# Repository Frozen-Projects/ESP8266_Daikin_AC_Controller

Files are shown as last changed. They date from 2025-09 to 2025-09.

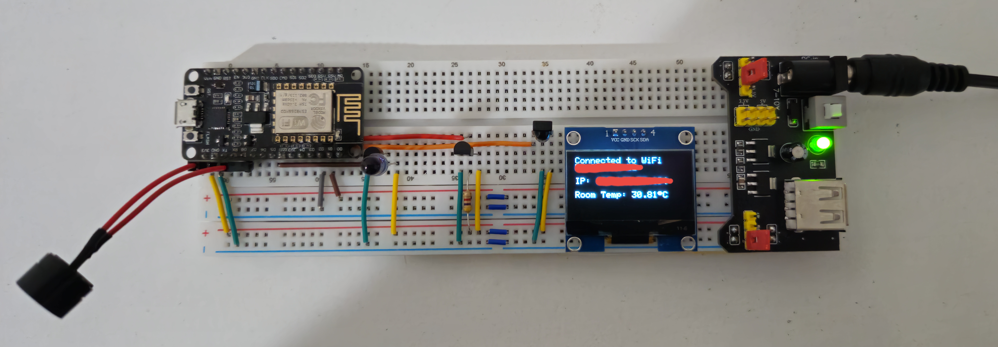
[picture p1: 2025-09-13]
Docs/ESP8266_Daikin_AC_Controller.jpg

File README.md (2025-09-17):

# ESP8266_Daikin_Controller
ESP8266 based Daikin AC Controller.

## FEATURES
- Turn on and off AC.
- Change temperature.
- Change fan speed.
- Set, change or clear auto off timer.
- It synchronized with original remote controller. (When you change something from remote controller, it will apply to ESP8266. But you can't see ESP8266 based changes on remote controller because it doesn't have an IR receiver. It just holds configurations.)
- Get room temperature with sensor (it refreshes at every 60 seconds).
- It has a web panel and API.

## LIBRARIES
You can install them from Arduino IDE libraries section.
- IRremoteESP8266 : https://github.com/crankyoldgit/IRremoteESP8266
- (Optional for temperature sensor) DallasTemperature : https://github.com/milesburton/Arduino-Temperature-Control-Library
- (Optional for temperature sensor) OneWire : https://www.pjrc.com/teensy/td_libs_OneWire.html
- (Optional for OLED) Adafruit GFX Lbrary
- (Optional for OLED) Adafruit SSD1305 / 1306 / SH110X

## IDE PLUGINS (OPTINAL IF YOU WANT TO STORE HTML AS A FILE)
- LittleFS Uploader : https://github.com/earlephilhower/arduino-littlefs-upload/releases/tag/1.5.4

## LittleFS USAGE (OPTINAL IF YOU WANT TO STORE HTML AS A FILE)
- Close Arduino IDE
- Move downloaded .vsix file to ``C:\Users\USERNAME\.arduinoIDE\plugins`` (not "plugin-storage". you can create "plugins" folder if you don't have already.)
- Open Arduino IDE
- Press ``CTRL + SHIFT + P`` buttons to open plugins list.
- Search LittleFS.
- Your files should be in ``SketchFolder/data``. This path is constant. Don't change it. If you delete something from there and do upload, it will remove that files.

## ARDUINO IDE ESP8266 INSTALLATION
- Add this to ``Arduino IDE / File / Preferences / Additional Boards Manager URLs`` ``http://arduino.esp8266.com/stable/package_esp8266com_index.json``
- Install ESP8266 Boards from ``Arduino IDE / Tools / Boards Manager / Search "esp8266 by ESP8266 Community"``
- Select ``NodeMCU MCU 1.0 (ESP-12E Module) as target device.``
- If Windows 11 can't see ESP8266 correctly in ``Device Manager``, you have to install this driver.
Unzip driver, right click device, select update driver, choose driver folder. </br> https://www.silabs.com/software-and-tools/usb-to-uart-bridge-vcp-drivers?tab=downloads

## HARDWARES
- 1X ESP8266 NodeMCU (ESP32 doesn't work with IRremoteESP8266. You can track its support from its issues)
- 1X 5mm 940nm 80 mW IR LED (Blue LED in scheme) (Pins: Long leg is (+) and short leg s (- / GRD)
- 1X S8050 Transistor (Transistor with N sign in scheme) (Pins: Emitter - Base - Collector)
- 1X 4.7K ohm Resistor
- 1X Breadboard (I used big one)
- 1X IR Receiver to sync. with original remote controller.
- (Optional) 1X Dallas DS1820 Temperature Sensor (Pins: GND - DQ - VDD)
- (Optional) OLED Display to print connected WiFi and LAN IP Address.
- (Optional) 1X Female barrel jack or Breadboard Power Supply Module for easy power delivery. You know, ESP8266'e USB input requires 3.3V input and finding that adapter can be hard. This allow me to use 5V adapters. I used power supply module.

## INFO ABOUT PHOTOGRAPH
Connection scheme is same with Fritzing but I did some cable management and used power module for cleaner product.

## UI Preview
index.html file and Github Pages show what UI will look like when you install this .ino file to your ESP8266. Preview file generated from GitHub Copilot. So, there can be some little differences. Auto-Off Timer Selection Box will open when AC is on.

## ROADMAP
HiveMQ based MQTT for remote access and mobile app. </br>
I have CGN IP. So, I needed to deploy a tunnelling solution to access it from outside of my local network. It worked but I don't have any always on local server. So, I will use additional ESP32 (because I don't want to put everything to this ESP8266) to connect HiveMQ like free and serverless MQTT service to receive orders like "turn on, off or change something" and send HTTP requests.

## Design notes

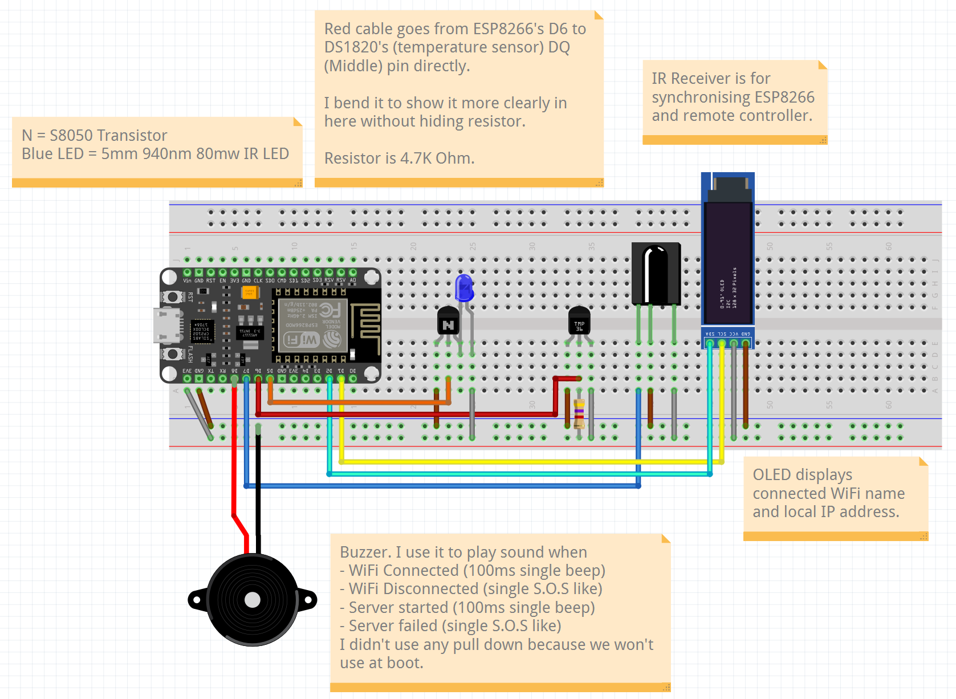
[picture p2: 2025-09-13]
Docs/ESP8266_Daikin_AC_Controller.png

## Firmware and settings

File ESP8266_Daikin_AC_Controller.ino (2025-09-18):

#include <Arduino.h>
#include <ESP8266WiFi.h>
#include <ESP8266WebServer.h>

// OTA INCLUDES.
#include <ESP8266mDNS.h>
#include <WiFiUdp.h>
#include <ArduinoOTA.h>

// IR INCLUDES.
#include <IRremoteESP8266.h>
#include <IRac.h>
#include <IRtext.h>
#include <IRsend.h>
#include <IRrecv.h>
#include <IRutils.h>
#include <ir_Daikin.h>

// TEMPERATURE SENSOR INCLUDES.
#include <OneWire.h>
#include <DallasTemperature.h>
#include <Wire.h>

// OLED INCLUDES.
#include <Adafruit_GFX.h>
#include <Adafruit_SH110X.h>

String notificationMessage = "";

#pragma region NETWORK_SETTINGS
const char* WIFI_SSID = "WIFI_SSID";
const char* WIFI_PASS = "WIFI_PASS";
const char* OTA_PASS = "YOUR_OTA_PASSWORD";

WiFiEventHandler onGotIPHandler;
WiFiEventHandler onDisconnectedHandler;
ESP8266WebServer server(80);
#pragma endregion NETWORK_SETTINGS

#pragma region BUZZER_AUDIO
#define PIN_BUZZER D8           // (GPIO13)
#define BEEP_FREQ 1600          // Hz
#define GAP_SHORT 250           // ms between beeps in a group
#define GAP_GROUP 600           // ms between groups

// Pattern step encoding: positive => tone ON for that many ms, negative => silence for abs(ms)
typedef struct
{
  const int16_t* steps;
  uint8_t count;
} BeepPattern;

static const int16_t BEEP_SUCCESS_STEPS[] =
{
  100,      // 100 ms tone
  -1
};

static const uint8_t BEEP_SUCCESS_COUNT = 1;

static const int16_t BEEP_SOS_STEPS[] =
{
  // • • •
  100, -GAP_SHORT, 100, -GAP_SHORT, 100, -GAP_GROUP,
  // — — —
  500, -GAP_SHORT, 500, -GAP_SHORT, 500, -GAP_GROUP,
  // • • •
  100, -GAP_SHORT, 100, -GAP_SHORT, 500
};

static const uint8_t BEEP_SOS_COUNT = sizeof(BEEP_SOS_STEPS) / sizeof(BEEP_SOS_STEPS[0]);

// Engine state
struct
{
  const int16_t* steps = nullptr;
  uint8_t count = 0;
  uint8_t index = 0;
  unsigned long stepStartMs = 0;
  bool active = false;
  bool toneOn = false;
} g_beep;

// Queue flags
volatile bool g_flagWifiConnected = false;
volatile bool g_flagWifiDisconnected = false;
volatile bool g_flagHttpStarted = false;
volatile bool g_flagHttpStopped = false;
volatile uint8_t g_pendingShortBeeps = 0;
static const uint16_t INTER_BEEP_GAP_MS = 120;
static bool g_inGap = false;
static unsigned long g_gapStartMs = 0;

inline void BeepEngine_start(const BeepPattern& p)
{
  g_beep.steps = p.steps;
  g_beep.count = p.count;
  g_beep.index = 0;
  g_beep.stepStartMs = millis();
  g_beep.active = (p.count > 0);
  g_beep.toneOn = false;
}

inline void BeepEngine_stop()
{
  noTone(PIN_BUZZER);
  g_beep.active = false;
  g_beep.toneOn = false;
}

void BeepEngine_update()
{
  if (g_inGap) {
    if (millis() - g_gapStartMs >= INTER_BEEP_GAP_MS)
    {
      g_inGap = false;
      static const BeepPattern P = { BEEP_SUCCESS_STEPS, BEEP_SUCCESS_COUNT };
      BeepEngine_start(P);
    }

    return;
  }

  if (!g_beep.active || g_beep.steps == nullptr || g_beep.count == 0) return;

  unsigned long now = millis();
  int16_t dur = g_beep.steps[g_beep.index];
  unsigned long stepDur = (dur >= 0 ? (unsigned long)dur : (unsigned long)(-dur));

  if (now - g_beep.stepStartMs == 0)
  {
    if (dur > 0) { tone(PIN_BUZZER, BEEP_FREQ); g_beep.toneOn = true; }
    else { noTone(PIN_BUZZER); g_beep.toneOn = false; }
  }

  if (now - g_beep.stepStartMs >= stepDur)
  {
    g_beep.index++;
    g_beep.stepStartMs = now;

    if (g_beep.index >= g_beep.count)
    {
      BeepEngine_stop();

      if (g_pendingShortBeeps > 0)
      {
        g_pendingShortBeeps--;
        g_inGap = true;
        g_gapStartMs = now;
        noTone(PIN_BUZZER);
      }
    }

    else
    {
      int16_t nd = g_beep.steps[g_beep.index];
      if (nd > 0) { tone(PIN_BUZZER, BEEP_FREQ); g_beep.toneOn = true; }
      else { noTone(PIN_BUZZER); g_beep.toneOn = false; }
    }
  }
}

inline void enqueue_Beep_Success()
{
  static const BeepPattern P = { BEEP_SUCCESS_STEPS, BEEP_SUCCESS_COUNT };
  if (!g_beep.active && !g_inGap) { BeepEngine_start(P); }
  else { if (g_pendingShortBeeps < 5) g_pendingShortBeeps++; }
}

inline void enqueue_Beep_SOS()
{
  static const BeepPattern P = { BEEP_SOS_STEPS, BEEP_SOS_COUNT };
  BeepEngine_start(P);
}
#pragma endregion BUZZER_AUDIO

#pragma region IR__LED
const uint16_t PIN_IRLED = D5;  // (GPIO14)
IRDaikinESP ac((uint16_t)PIN_IRLED);
#pragma endregion IR_LED

#pragma region IR_RECEIVER
const uint16_t kRecvPin = D7;  // D5 on ESP8266
const uint32_t kBaudRate = 115200;
const uint16_t kCaptureBufferSize = 1024;
const uint8_t kTimeout = 50;  // Timeout in milliseconds

// Use turn on the save buffer feature for more complete capture coverage.
IRrecv irrecv(kRecvPin, kCaptureBufferSize, kTimeout, true);
#pragma endregion IR_RECEIVER

#pragma region TEMPERATURE_SENSOR
#define PIN_TEMPERATURE D6      // (GPIO12)
OneWire oneWire(PIN_TEMPERATURE);
DallasTemperature sensors(&oneWire);
float currentTemperature = -127.0;
unsigned long lastTempUpdate = 0;
const unsigned long TEMP_UPDATE_INTERVAL = 60000;  // 1 minute
#pragma endregion TEMPERATURE_SENSOR

#pragma region AC_SETTINGS
bool acPower = false;
uint8_t acTemp = 23;
uint8_t acFanSpeed = 3;
uint8_t acMode = kDaikinCool;
unsigned long acTimerStart = 0;
unsigned long acTimerDuration = 0;        // milliseconds (If you set this to "0" in API, it will disable auto turn off timer.)
unsigned long LastOffTimerDuration = 0;   // We use this to prevent sending same timer.
bool bIsOffTimerActive = false;
#pragma endregion AC_SETTINGS

#pragma region OLED
#define OLED_SCL   D1   // Also known as SCK (GPIO5)
#define OLED_SDA   D2   // (GPIO4)
#define OLED_RESET -1   // not used on most 4-pin modules
#define SCREEN_WIDTH  128
#define SCREEN_HEIGHT 64
Adafruit_SH1106G display(SCREEN_WIDTH, SCREEN_HEIGHT, &Wire, OLED_RESET);

void displayOLED()
{
  display.clearDisplay();
  display.setTextSize(1);
  display.setTextColor(SH110X_WHITE);
  display.setCursor(0, 0);

  display.println("Connected to WiFi");
  display.println(WIFI_SSID);
  display.println("");

  display.print("IP: ");
  display.println(WiFi.localIP().toString());
  display.println("");

  display.print("Room Temp: ");
  display.print(currentTemperature);
  display.write(247); // ASCII Degree symbol.
  display.print("C");
  display.println("");

  if (acTimerDuration > 0)
  {
    unsigned long elapsed = millis() - acTimerStart;
    unsigned long remainingTime = (elapsed >= acTimerDuration) ? 0UL : (acTimerDuration - elapsed);
    int remainingHours = remainingTime / 3600000UL;
    int remainingMins  = (remainingTime / 60000UL) % 60;
    String TimeString = String(remainingHours) + "h " + String(remainingMins) + "m ";

    display.println("Remaining Time: ");
    display.print(TimeString);
    display.println("");
  }

  display.display();
}
#pragma endregion OLED

// WebUI
void handleRoot()
{
  String html = "<html><head>";
  html += "<meta charset=\"UTF-8\">";
  html += "<title>Daikin AC Control</title>";
  html += "<meta name='viewport' content='width=device-width, initial-scale=1'>";
  html += "<style>";
  html += "body { font-family: Arial, sans-serif; margin: 20px; text-align: center; background-color: black; color: white; }";
  html += "button { background-color: #4CAF50; border: none; color: white; padding: 15px 32px; margin: 10px; text-align: center; text-decoration: none; display: inline-block; font-size: 16px; border-radius: 8px; cursor: pointer; }";
  html += ".off { background-color: #f44336; }";
  html += ".temp { background-color: #008CBA; }";
  html += ".refresh { background-color: #FF9800; }";
  html += ".clear { background-color: #9C27B0; }";
  html += ".sensor { font-size: 1.2em; font-weight: bold; margin: 20px 0; padding: 10px; background-color: #333; border-radius: 5px; color: #fff; }";
  html += ".error { color: #ff6b6b; }";
  html += ".notification { background-color: #2196F3; color: white; padding: 10px; margin: 10px 0; border-radius: 5px; animation: fadeOut 5s forwards; }";
  html += "select { padding: 10px; font-size: 16px; border-radius: 8px; background-color: #008CBA; color: white; margin: 10px; border: none; cursor: pointer; }";
  html += "select:focus { outline: none; }";
  html += ".temp-control, .fan-control, .timer-control { margin: 15px 0; }";
  html += "@keyframes fadeOut { from { opacity: 1; } to { opacity: 0; display: none; } }";
  html += "</style>";
  html += "<script>";
  
  html += "function refreshTemp() {";
  html += "  fetch('/status')";
  html += "    .then(response => response.json())";
  html += "    .then(data => {";
  
  html += "      const tempEl = document.getElementById('roomTemp');";
  html += "      if (data.roomTemperature > -100) {";
  html += "        tempEl.innerText = data.roomTemperature.toFixed(1) + '\\u00B0C';";
  html += "        tempEl.className = '';";
  html += "      } else {";
  html += "        tempEl.innerText = 'Sensor Error';";
  html += "        tempEl.className = 'error';";
  html += "      }";

  html += "      const acStatus = document.getElementById('acStatus');";
  html += "      if (acStatus) acStatus.innerText = data.power ? 'ON' : 'OFF';";

  html += "      const setTemp = document.getElementById('setTemp');";
  html += "      if (setTemp) setTemp.innerText = String(data.temperature) + '\\u00B0C';";
  html += "      const tempSelect = document.getElementById('tempSelect');";
  html += "      if (tempSelect && tempSelect.value !== String(data.temperature)) {";
  html += "        tempSelect.value = String(data.temperature);";
  html += "      }";

  html += "      const fanSelect = document.getElementById('fanSelect');";
  html += "      if (fanSelect && fanSelect.value !== String(data.fanSpeed)) {";
  html += "        fanSelect.value = String(data.fanSpeed);";
  html += "      }";
  
  html += "      const timerStatus = document.getElementById('timerStatus');";
  html += "      if (data.timerActive) {";
  html += "        const total = Math.max(0, Math.floor(data.timerRemaining));";
  html += "        const hours = Math.floor(total / 3600);";
  html += "        const mins = Math.floor((total % 3600) / 60);";
  html += "        const secs = total % 60;";
  html += "        timerStatus.innerHTML = 'Timer: ' + hours + 'h ' + mins + 'm ' + secs + 's remaining';";
  html += "        timerStatus.style.display = 'block';";
  
  html += "        const timer_value = parseInt(data.timerDuration);";
  html += "         if(timer_value > 0) {";
  html += "           const duration = (timer_value / 60);";
  html += "           timerSelect.value = String(duration);";
  html += "         }";

  html += "      } else {";
  html += "        timerStatus.style.display = 'none';";
  html += "        timerSelect.value = String(0);";
  html += "      }";

  html += "      const timerControl = document.querySelector('.timer-control');";
  html += "      if (timerControl) {";
  html += "        timerControl.style.display = data.power ? 'block' : 'none';";
  html += "      }";
  
  html += "      if (!data.power && timerStatus) timerStatus.style.display = 'none';";
  html += "    });";
  html += "}";
  
  html += "function changeTemp() {";
  html += "  const temp = document.getElementById('tempSelect').value;";
  html += "  location.href = '/temp?value=' + temp;";
  html += "}";
  
  html += "function changeFan() {";
  html += "  const fan = document.getElementById('fanSelect').value;";
  html += "  location.href = '/fan?value=' + fan;";
  html += "}";
  
  html += "function setTimer() {";
  html += "  const timer = document.getElementById('timerSelect').value;";
  html += "  location.href = '/timer?value=' + timer;";
  html += "}";
  
  html += "function clearTimer() {";
  html += "  location.href = '/clear_timer';";
  html += "}";
  
  html += "window.onload = function() {";
  html += "  refreshTemp();";
  html += "  setTimeout(function() {";
  html += "    const notification = document.getElementById('notification');";
  html += "    if (notification) notification.style.display = 'none';";
  html += "  }, 5000);";
  html += "};";
  html += "setInterval(refreshTemp, 1000);";
  html += "</script>";
  html += "</head><body>";
  html += "<h1>Daikin AC Control</h1>";

  if (notificationMessage.length() > 0) {
    html += "<div id='notification' class='notification'>" + notificationMessage + "</div>";
    notificationMessage = "";
  }

  html += "<div class='sensor'>Room Temperature: <span id='roomTemp'>";

  if (currentTemperature > -100)
  {
    html += String(currentTemperature, 1) + "&deg;C";
  }

  else
  {
    html += "<span class='error'>Sensor Error</span>";
  }
  html += "</span></div>";

  html += "<button class='refresh' onclick='location.href=\"/refresh_temp\"'>Refresh Temperature</button><br>";
  html += "<p>AC Status: <span id='acStatus'>" + String(acPower ? "ON" : "OFF") + "</span></p>";
  html += "<p>Set Temperature: <span id='setTemp'>" + String(acTemp) + "&deg;C</span></p>";
  html += "<button onclick='location.href=\"/on\"'>Turn ON</button>";
  html += "<button class='off' onclick='location.href=\"/off\"'>Turn OFF</button><br>";
  html += "<div class='temp-control'>";
  html += "<label for='tempSelect'>Select Temperature: </label>";
  html += "<select id='tempSelect' onchange='changeTemp()'>";
  
  for (int t = 18; t <= 32; t++)
  {
    html += "<option value='" + String(t) + "'";
    if (t == acTemp) html += " selected";
    html += ">" + String(t) + "&deg;C</option>";
  }
  
  html += "</select>";
  html += "</div>";
  html += "<div class='fan-control'>";
  html += "<label for='fanSelect'>Select Fan Speed: </label>";
  html += "<select id='fanSelect' onchange='changeFan()'>";
  html += "<option value='10'" + String(acFanSpeed == kDaikinFanAuto ? " selected" : "") + ">Auto</option>";
  
  for (int f = 1; f <= 5; f++)
  {
    html += "<option value='" + String(f) + "'";
    if (f == acFanSpeed) html += " selected";
    html += ">" + String(f) + "</option>";
  }

  html += "<option value='11'" + String(acFanSpeed == kDaikinFanQuiet ? " selected" : "") + ">Quiet</option>";
  html += "</select>";
  html += "</div>";
  html += "<div class='timer-control' style='display: " + String(acPower ? "block" : "none") + ";'>";
  html += "<label for='timerSelect'>Auto-Off Timer: </label>";
  html += "<select id='timerSelect' onchange='setTimer()'>";
  html += "<option value='0'" + String(acTimerDuration == 0 ? " selected" : "") + ">No Timer</option>";
  
  for (int h = 1; h <= 9; h++)
  {
    html += "<option value='" + String(h) + "'";
    if (acTimerDuration == (unsigned long)h * 3600000UL) html += " selected";
    html += ">" + String(h) + " Hour" + (h > 1 ? "s" : "") + "</option>";
  }

  html += "</select>";

  html += "<p id='timerStatus' style='display: " + String(acTimerDuration > 0 && acPower ? "block" : "none") + ";'>";
  if (acTimerDuration > 0 && acPower)
  {
    unsigned long elapsed = millis() - acTimerStart;
    unsigned long remainingTime = (elapsed >= acTimerDuration) ? 0UL : (acTimerDuration - elapsed);
    int remainingHours = remainingTime / 3600000UL;
    int remainingMins  = (remainingTime / 60000UL) % 60;
    int remainingSecs  = (remainingTime / 1000UL) % 60;
    html += "Timer: " + String(remainingHours) + "h " + String(remainingMins) + "m " + String(remainingSecs) + "s remaining";
  }

  html += "</p>";
  html += "</div>";
  html += "</body></html>";

  server.send(200, "text/html", html);
}

void handleStatus()
{
  String json = "{";
  json += "\"power\":" + String(acPower ? "true" : "false") + ",";
  json += "\"temperature\":" + String(acTemp) + ",";
  json += "\"roomTemperature\":" + String(currentTemperature) + ",";
  json += "\"mode\":" + String(acMode) + ",";
  json += "\"fanSpeed\":" + String(acFanSpeed) + ",";
  json += "\"timerActive\":" + String(bIsOffTimerActive ? true : false);

  if (acTimerDuration > 0)
  {
    unsigned long elapsed = millis() - acTimerStart;
    unsigned long remainingTime = (elapsed >= acTimerDuration) ? 0UL : (acTimerDuration - elapsed);
    
    json += ",\"timerRemaining\":" + String(remainingTime / 1000UL);
    json += ",\"timerDuration\":" + String(acTimerDuration / 60000UL);
  }

  else
  {
    json += ",\"timerRemaining\":0";
    json += ",\"timerDuration\":0";
  }

  json += "}";

  server.send(200, "application/json", json);
}

// This function is called every minute. So, we use it to update OLED, too
void updateTemperature()
{
  Serial.println("Requesting temperature...");
  sensors.requestTemperatures();

  float tempC = sensors.getTempCByIndex(0);

  if (tempC != DEVICE_DISCONNECTED_C)
  {
    currentTemperature = tempC;
    Serial.print("Temperature: ");
    Serial.println(currentTemperature);
  }

  else
  {
    Serial.println("Error: Could not read temperature data");
  }

  lastTempUpdate = millis();
  displayOLED();
}

void handleRefreshTemp()
{
  updateTemperature();
  
  server.sendHeader("Location", "/");
  server.send(303);
}

void setDefaultSettings()
{
  ac.setFan(acFanSpeed);
  ac.setMode(acMode);
  ac.setTemp(acTemp);
  ac.setSwingVertical(false);
  ac.setSwingHorizontal(false);
  ac.setQuiet(false);
  ac.setPowerful(false);
}

void sendAcCommand()
{
  irrecv.pause();

  ac.setPower(acPower);
  ac.setTemp(acTemp);
  ac.setFan(acFanSpeed);

  if (acTimerDuration > 0 && LastOffTimerDuration != acTimerDuration)
  {
    ac.enableOffTimer(acTimerDuration / 60000UL);
  }

  else if (acTimerDuration == 0)
  {
    ac.disableOffTimer();
  }

  ac.send();
  LastOffTimerDuration = acTimerDuration;

  Serial.println("Sending IR Command:");
  Serial.print("Power: "); Serial.println(acPower ? "ON" : "OFF");
  Serial.print("Temperature: "); Serial.println(acTemp);
  Serial.print("Mode: "); Serial.println(acMode);
  Serial.print("Fan Speed: "); Serial.println(acFanSpeed);
  Serial.print("Auto-Off Timer: "); Serial.println(acTimerDuration > 0 ? "YES" : "NO");
  
  irrecv.resume();
}

void handleOn()
{
  acPower = true;

  sendAcCommand();
  
  server.sendHeader("Location", "/");
  server.send(303);
}

void handleOff()
{
  acPower = false;
  acTimerDuration = 0;
  acTimerStart = 0;
  bIsOffTimerActive = false;
  
  sendAcCommand();
  
  server.sendHeader("Location", "/");
  server.send(303);
}

// API only.
void handleToggle()
{
  if (acPower == true)
  {
    handleOff();
    return;
  }

  else
  {
    handleOn();
    return;
  }
}

void handleTemp()
{
  if (server.hasArg("value"))
  {
    int temp = server.arg("value").toInt();
    if (temp >= 18 && temp <= 32)
    {
      acTemp = temp;
      if (acPower)
      {
        sendAcCommand();
      }
    }
  }

  server.sendHeader("Location", "/");
  server.send(303);
}

void handleFan()
{
  if (server.hasArg("value"))
  {
    int fan = server.arg("value").toInt();
    if ((fan >= 1 && fan <= 5) || fan == kDaikinFanAuto || fan == kDaikinFanQuiet)
    {
      acFanSpeed = fan;
      
      if (acPower)
      {
        sendAcCommand();
      }
    }
  }

  server.sendHeader("Location", "/");
  server.send(303);
}

void handleClearTimer()
{
  const String Message = "Timer has been cleared"; 
  notificationMessage = Message;
  Serial.println(Message);

  acTimerDuration = 0;
  acTimerStart = 0;
  LastOffTimerDuration = 0;
  bIsOffTimerActive = false;

  sendAcCommand();
  displayOLED();
  
  server.sendHeader("Location", "/");
  server.send(303);
}

void handleTimer()
{
  if (!server.hasArg("value") || !acPower)
  {
    server.sendHeader("Location", "/");
    server.send(303);

    return;
  }

  const int hours = server.arg("value").toInt();
    
  if (hours == 0)
  {
    // It has internal displayOLED and server functions.
    handleClearTimer();

    server.sendHeader("Location", "/");
    server.send(303);

    return;
  }

  else if (hours >= 1 && hours <= 9)
  {
    String message = "Timer set for " + String(hours) + " hour" + (hours != 1 ? "s" : "");
    notificationMessage = message;

    bIsOffTimerActive = true;
    acTimerDuration = (unsigned long)hours * 3600000UL;
    acTimerStart = millis();

    sendAcCommand();

    server.sendHeader("Location", "/");
    server.send(303);
  }
}

void setupIRReceiver()
{
  irrecv.enableIRIn();  // Start the receiver
  Serial.print("IR Receiver initialized on pin : ");
  Serial.println(kRecvPin);
}

void printDaikingProtocol(const decode_type_t protocol)
{
  switch (protocol)
  {
    case DAIKIN:
      Serial.print("Decoded DAIKIN");
      break;
    case DAIKIN2:
      Serial.print("Decoded DAIKIN2");
      break;
    case DAIKIN216:
      Serial.print("Decoded DAIKIN216");
      break;
    case DAIKIN128:
      Serial.print("Decoded DAIKIN128");
      break;
    case DAIKIN152:
      Serial.print("Decoded DAIKIN152");
      break;
    case DAIKIN64:
      Serial.print("Decoded DAIKIN64");
      break;
    default:
      Serial.print("Decoded ");
      Serial.print(typeToString(protocol));
  }
}
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
void loop()
{
  ArduinoOTA.handle();
  server.handleClient();

  if (g_flagWifiConnected)   { enqueue_Beep_Success(); g_flagWifiConnected = false; }
  if (g_flagWifiDisconnected){ enqueue_Beep_SOS();  g_flagWifiDisconnected = false; }
  if (g_flagHttpStarted)     { enqueue_Beep_Success(); g_flagHttpStarted = false; }
  if (g_flagHttpStopped)     { enqueue_Beep_SOS();  g_flagHttpStopped = false; }
  BeepEngine_update();

  if (millis() - lastTempUpdate >= TEMP_UPDATE_INTERVAL)
  {
    updateTemperature();
  }

  if (acTimerDuration > 0 && acPower)
  {
    if (millis() - acTimerStart >= acTimerDuration)
    {
      acPower = false;
      acTimerDuration = 0;
      acTimerStart = 0;
      LastOffTimerDuration = 0;
      bIsOffTimerActive = false;

      sendAcCommand();
      Serial.println("Timer expired - AC turned off");
    }
  }

  processIrMessage();
}

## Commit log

2025-09-09 New File and Folder Structure
    [ESP8266_Daikin_AC_Controller.fzz]
2025-09-12 Variable Updates
    Timer, fan speed and AC temperature limits updated according to original remote.
2025-09-12 Clear Timer Moved To Selection Box
2025-09-12 Set and Clear Timer Improvements
2025-09-14 v2.1 BugFix: Auto Timer
    sendAcCommand() didn't send necessary timer functions. So, our IR LED send timer side empty signals and our IR sensor received them. For this reason, timer looks not configured. And timer wouldn't auto turn off AC.
    Problem solved.
    [ESP8266_Daikin_AC_Controller.ino]
2025-09-14 v2.2
    sendAcCommands() stops IR sensor for a short time to prevent re-read itself. We prevented to send same timer value with each command.
    [ESP8266_Daikin_AC_Controller.ino]
